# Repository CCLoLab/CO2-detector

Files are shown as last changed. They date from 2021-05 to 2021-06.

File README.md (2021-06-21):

# CO2-detector
For better office air quality.

The detector will alarm you when the CO2 concentration is high enough to make you sleepy.

## Wiring
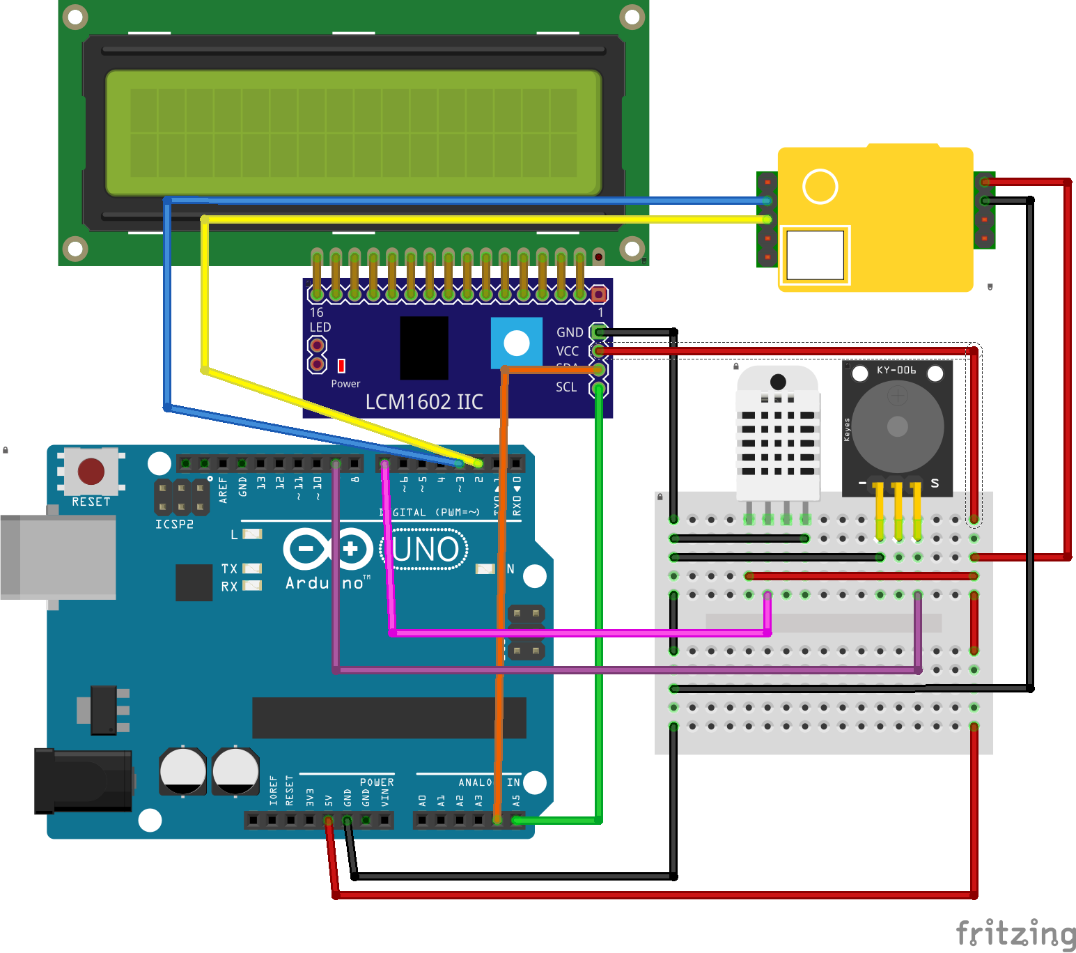
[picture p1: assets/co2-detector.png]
Graphical wiring diagram

__Note__: The temperature and humidity sensor in the diagram is DHT22 and it is possible to replace it with DHT11 for lower costs.
In order to use DHT11, you have to edit the definition macro from `#define DHTTYPE DHT22` to `#define DHTTYPE DHT11`.

## Required Libraries
The following libraries are necessary for reading sensor data and displaying.
* __LiquidCrystal I2C__ by Marco Schwartz
* __DHT sensor library__ by Adafruit

Both are available in Arduino IDE library manager.

## 3D Printing Notes
The 3D mesh files are `co2-detector_case.stl` and `co2-detector_lid.stl` under assests directory. It is only tested on Ultimaker 2+ with adhesion option checked, infill 40% and layer height 1.5. The material is white ABS.

__Note__: The latch of the case is fragile. Please do not assemble the case and the lid by force.

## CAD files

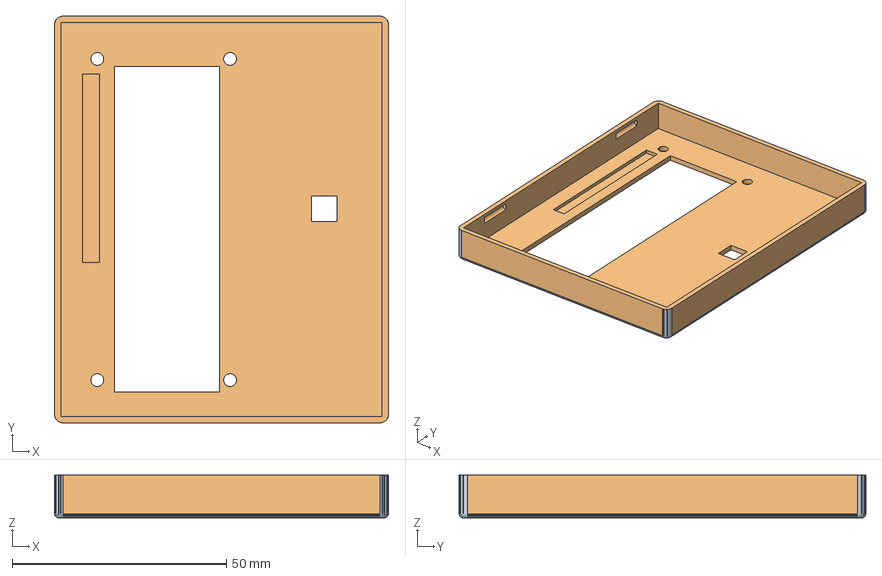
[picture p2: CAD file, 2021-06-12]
assets/co2-detector_lid.FCStd
78.0 x 95.0 x 10.0 mm
Body (Meshed)

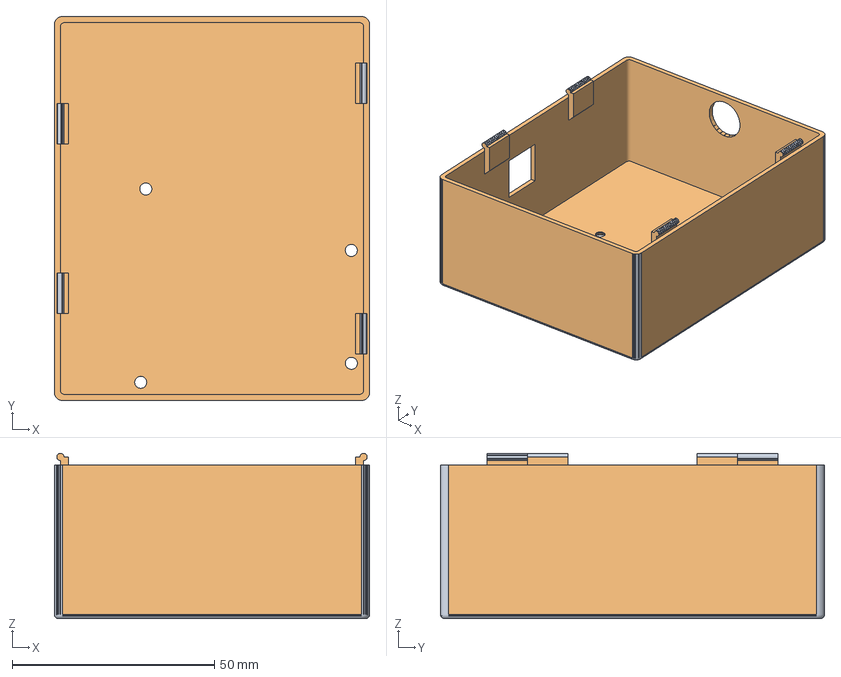
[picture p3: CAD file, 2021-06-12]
assets/co2-detector_case.FCStd
78.0 x 95.0 x 40.9 mm
Body (Meshed)

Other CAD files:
assets/co2-detector_case.stl
assets/co2-detector_lid.stl

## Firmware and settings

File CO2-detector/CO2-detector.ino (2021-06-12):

#include <LiquidCrystal_I2C.h>
#include <SoftwareSerial.h>
#include <Wire.h>
#include "DHT.h"
#define DHTTYPE DHT22

const byte Buzzer = 9;
const byte DHTPIN = 7;
const byte CO2Rx = 2;
const byte CO2Tx = 3;
const byte ACK = 10;

LiquidCrystal_I2C lcd(0x27, 16, 2);
DHT dht(DHTPIN, DHTTYPE);
SoftwareSerial co2meter(CO2Rx, CO2Tx);

typedef struct DHTData
{
  float temperature;
  float humidity;  
};

const int threshold = 1500;
unsigned long preheat_time = 180000; // preheat 3 min
const unsigned long inact_time = 3600000; //millis
unsigned long enter_time = 0;
unsigned long current_time = 0;
byte read_co2meter[9] = {0xFF, 0x01, 0x86, 0x00, 0x00, 0x00, 0x00, 0x00, 0x79};
bool isPreheating = true;

enum States { Normal, Emergency, Inactive};
States state = Normal;

void setup()
{
  lcd.init(); //16col, 2row, backlight default
  dht.begin();
  for(int i = 0; i < 3; i++) {
    lcd.backlight();
    delay(200);
    lcd.noBacklight();
    delay(200);
    co2meter.begin(9600);
  }
  lcd.backlight();
  lcd.setCursor(0, 0);
  lcd.print("CO2 Detector");
  delay(1000);
  lcd.setCursor(0, 1);
  lcd.print("Good Day!");
  delay(3000);
  lcd.clear();
}

void loop()
{
  if(isPreheating)
  {
    if(millis() > preheat_time){
      isPreheating = false;  
    }
  }
  switch (state)
  {
    case Normal:
      standard_procedure();
      break;
    case Inactive:
      inactive_period();
      break;
    case Emergency:
      emergency_beep();
      break;    
  }
  delay(10000);
}

byte getChecksum(byte* packet)
{
  byte checksum;
  for(int i = 1; i < 8; i++)
  {
    checksum += packet[i];
  }
  checksum = 0xFF - checksum + 0x01;
  return checksum;
}

int getCO2ppm()
{
  byte response[9];
  co2meter.write(read_co2meter, 9);
  co2meter.readBytes(response, 9);
  if(response[8] != getChecksum(response))
  {
    return -1;  
  }
  int responseHIGH = (int)response[2];
  int responseLOW = (int)response[3];
  return (256*responseHIGH)+responseLOW;
}

DHTData getTemperatureHumidity()
{
  DHTData data;
  data.humidity = dht.readHumidity();
  data.temperature = dht.readTemperature();
  // Reading temperature or humidity takes about 250 milliseconds
  delay(250);
  if(isnan(data.humidity) || isnan(data.temperature))
  {
    data.humidity = -1;
    data.temperature = -1;  
  }
  return data;
}

void updateDisplay(int ppm, DHTData data)
{
  lcd.clear();
  lcd.setCursor(0, 0);
  if(isPreheating)
  {
    lcd.print("CO2:Preheat ");
    unsigned int time_left = (preheat_time-millis())/1000;
    lcd.print(time_left);
    lcd.print("s");
  }
  else
  {
    lcd.print("CO2: ");
    lcd.print(ppm);
    lcd.print("ppm");  
  }
  lcd.setCursor(0, 1);
  lcd.print(data.temperature);
  lcd.print("*C  ");
  lcd.print(data.humidity);
  lcd.print("%");
}
  
void standard_procedure()
{
  int ppm = getCO2ppm();
  DHTData comfort = getTemperatureHumidity();
  updateDisplay(ppm, comfort);
  
  if(ppm > threshold)
  {
    state = Emergency;
    enter_time = millis();
  }
  else
  {
    state = Normal;  
  }
}

void emergency_beep()
{
  for (int j=0; j < 3; j++)
  {
    for (int i=0; i < 3; i++)
    {
      tone(Buzzer, 440, 200);
      delay(600);
      noTone(Buzzer);
    }
    delay(1000);
  }
  state = Inactive;
}

void inactive_period()
{
  int ppm = getCO2ppm();
  DHTData comfort = getTemperatureHumidity();
  updateDisplay(ppm, comfort);
 
  current_time = millis();
  if( (current_time - enter_time) > inact_time)
  {
    state = Normal;  
  }
  else
  {
    state = Inactive;  
  }
}

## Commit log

2021-05-12 The current version of program on our prototype
2021-05-18 Change CO2 meter preheating time to exact 3 min and show a count-down timer
2021-05-19 Add wiring diagram and BOM
    [co2-detector.fzz]
2021-06-01 Add sensor case design.
    [co2-detector_case.FCStd]
2021-06-08 Update the source files of the case of the sensor system
    [co2-detector_case.FCStd, co2-detector_case.stl, co2-detector_lid.FCStd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]
2021-06-12 Update 3D models and use DHT22 sensor as default
    [co2-detector_case.FCStd, co2-detector_case.stl, co2-detector_lid.FCStd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]
2021-06-21 Add 3D printing description in README
